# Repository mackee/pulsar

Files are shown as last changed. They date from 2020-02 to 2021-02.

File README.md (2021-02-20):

# Pulsar - The functional keyboard for creators

## 部品の不足や不具合, その他のお問い合わせ

Twitterの私のアカウントまでDMをしてください [@mackee\_w](https://github.com/mackee_w)

## ビルドガイド

このビルドガイドはRev.2(11キー)版のビルドガイドです。Rev.1(9キー+OLED付き) のビルドガイドはこちら

https://gist.github.com/mackee/b5231e5609be889129ee4aa5c9ab0aaa

### 同梱しているもの

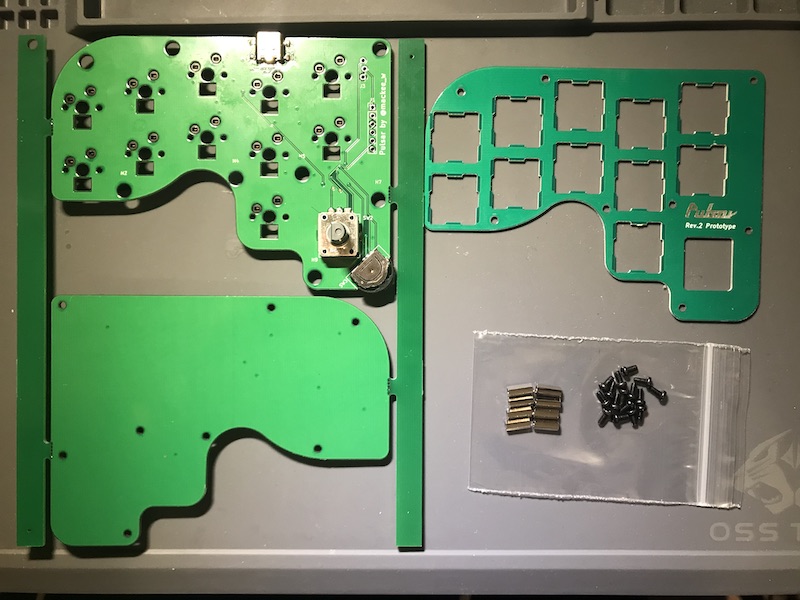
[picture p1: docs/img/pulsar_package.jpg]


#### Pulsar本体基板

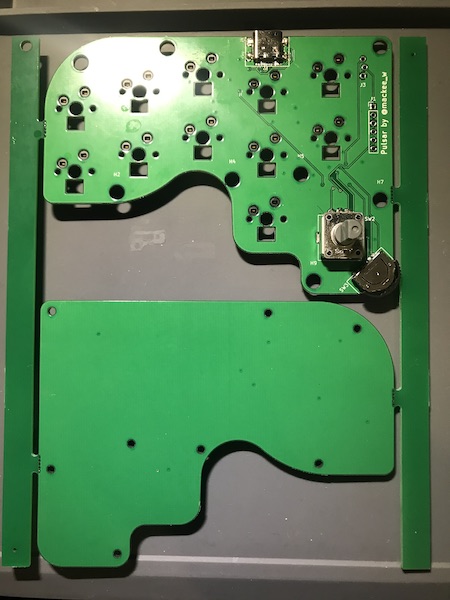
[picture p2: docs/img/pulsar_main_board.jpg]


メイン基板と、LEDがついたボトムプレートが一体になっています。

#### トッププレート

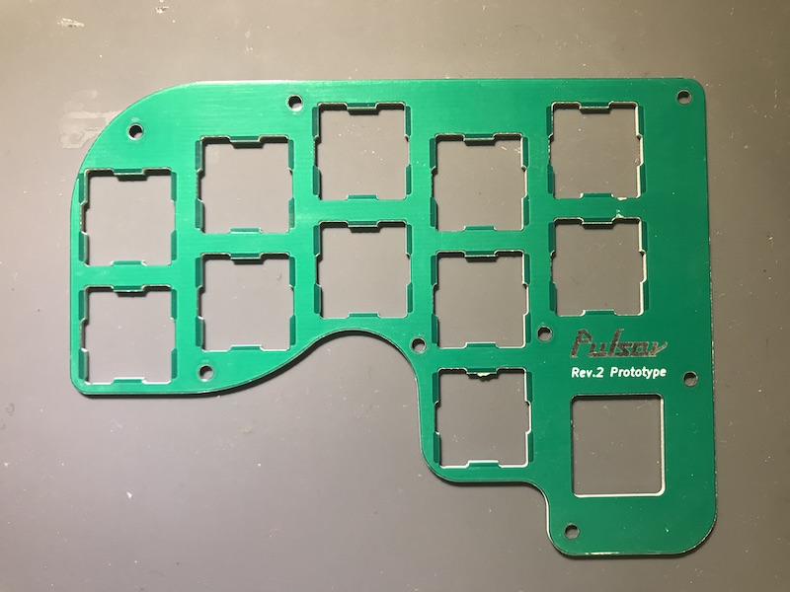
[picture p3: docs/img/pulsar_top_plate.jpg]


本体基板とは別に添付しています。

#### ネジ袋

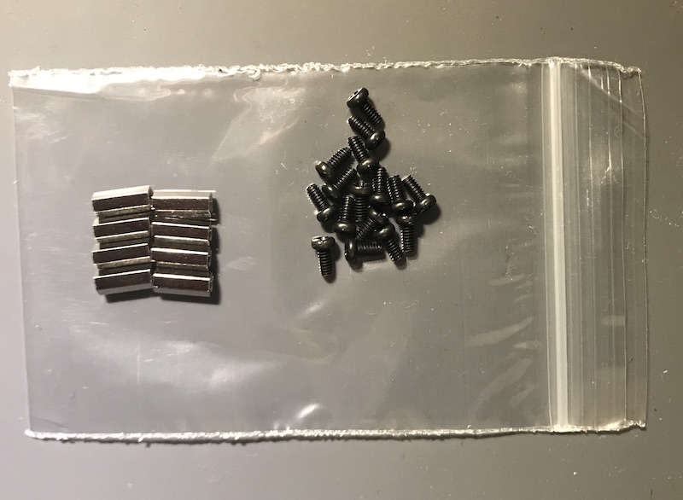
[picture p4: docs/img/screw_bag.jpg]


ネジが入った袋です。袋の中には以下の物が含まれています。

* M2 スペーサー 高さ7.5mm x 8本
* M2 ネジ x 16本

### 別途使用に必要なもの

#### キースイッチ x 11個

Cherry MX互換のキースイッチに対応しています。

[Kailh BOX](https://yushakobo.jp/shop/kailh-box/), [Kailh Speed](https://yushakobo.jp/shop/kailh-speed/), [Gateronスイッチ](https://yushakobo.jp/shop/a0200ga/)の適合を確認しています

#### キーキャップ x 11個

入手されたキースイッチに適合するキーキャップが必要です

#### ノブ/つまみ

親指ロータリーエンコーダ部分に使用するノブです。

軸φ6.1に対応しているつまみが使用できます。また、直径2.3cm以上のつまみはキーキャップと干渉します。

秋月電子で売られている[K-59](http://akizukidenshi.com/catalog/g/gP-12529/)や、千石電商で扱いがある[BR-20](https://www.sengoku.co.jp/mod/sgk_cart/detail.php?code=6A8D-DNEV)が使用できることを確認しています。

### 別途組み立てに必要な道具

* \+ 精密ドライバー
* ラジオペンチ

### 組み立て方

#### 1. 基板を分割する

Pulsar基板本体をメイン基板とボトムプレートに分割します。

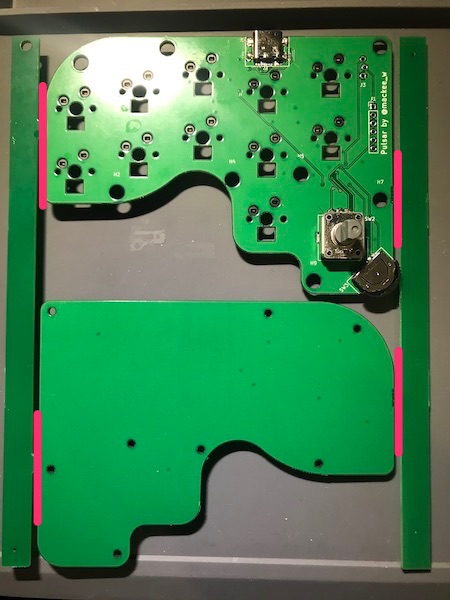
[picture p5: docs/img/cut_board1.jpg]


4箇所あるので、できるだけ近い部分を持ちつつ折ってください。写真のようにラジオペンチを使うときれいに折れます。

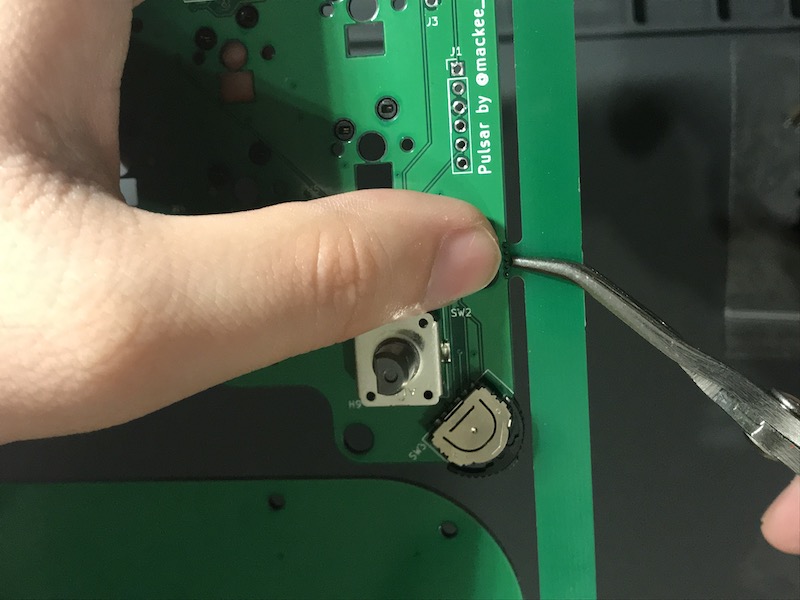
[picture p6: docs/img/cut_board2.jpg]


#### 2. ボトムプレートにスペーサーを立てる

ネジ袋からスペーサーを8個全部と、黒いネジを8個取り出します。

ボトムプレートの何も部品がない面から、ネジを差し込み、反対側からスペーサーを取り付けます。

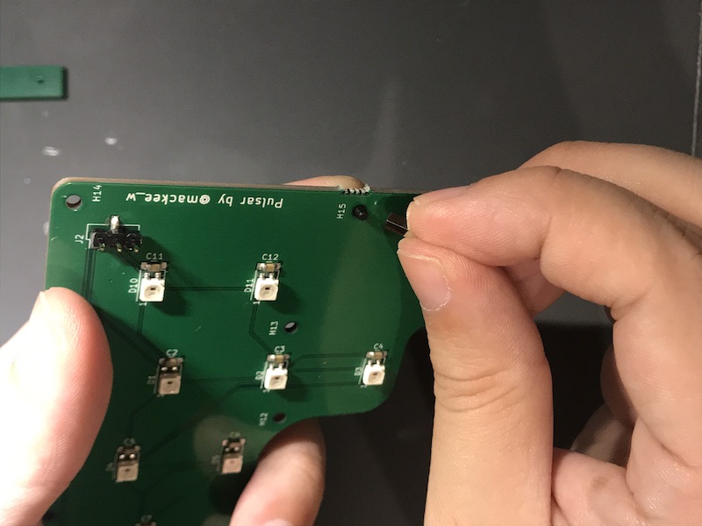
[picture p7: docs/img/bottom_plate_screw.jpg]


このとき、はじめは手で軽く締めていって、最後に精密ドライバーでネジを、ラジオペンチでスペーサーを持って固く締めます。

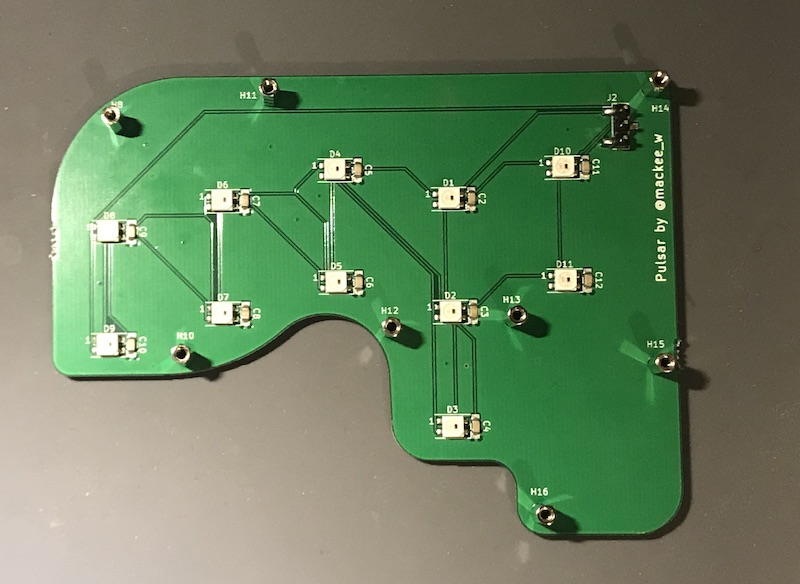
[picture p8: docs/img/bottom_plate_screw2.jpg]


8箇所ある穴すべてにスペーサーを立てます。

#### 3. メイン基板をボトムプレートに重ねる

メイン基板を、スペーサーを立てたボトムプレートの上に重ねます。

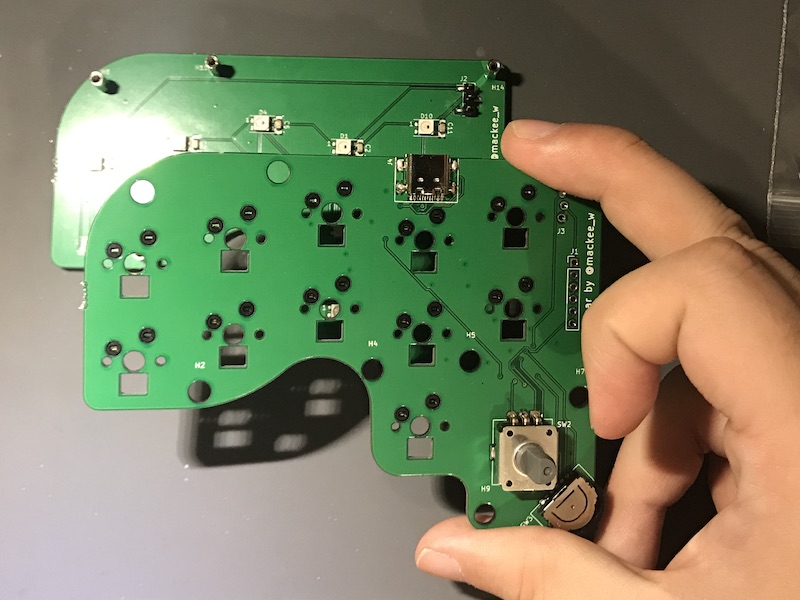
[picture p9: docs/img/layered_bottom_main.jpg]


メイン基板の取り付け穴はスペーサーの直径よりも大きいので、穴の中にスペーサーを通すようにします。

また、ロータリーエンコーダを右下にしたときに、ボトムプレートには 3本のピンヘッダーが、メイン基板にはピンヘッダを通すための穴があります。

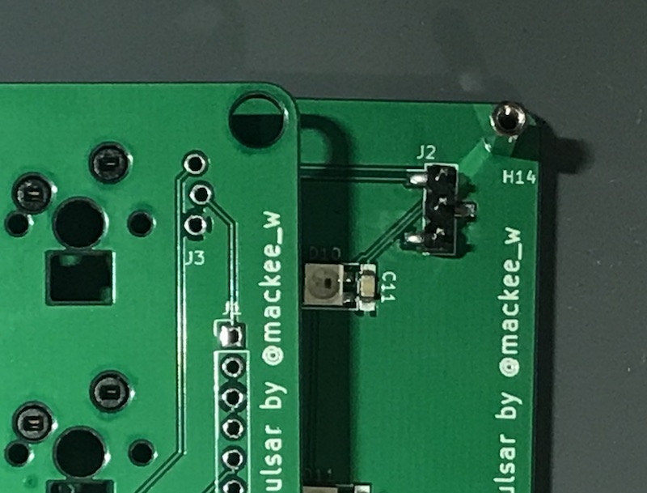
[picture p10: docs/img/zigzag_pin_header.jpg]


電気的に接触するため、メイン基板側の真ん中の穴が少しずれています。重ねたときに、ボトムプレートのピンがメイン基板の穴に刺さるようにします。

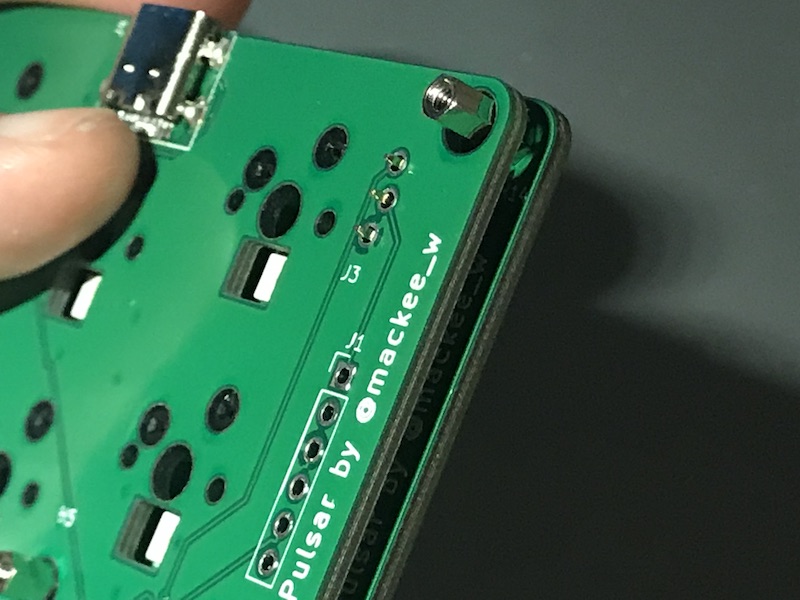
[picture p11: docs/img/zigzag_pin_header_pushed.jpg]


止まるまでグググッと押し込みます。

#### 4. トッププレートを取り付ける

ボトムプレートに、メイン基板を重ねた物の上にさらに、トッププレートを重ねます。

スペーサーの位置とトッププレートの位置を合わせて、トッププレートを残りのネジで固定します。

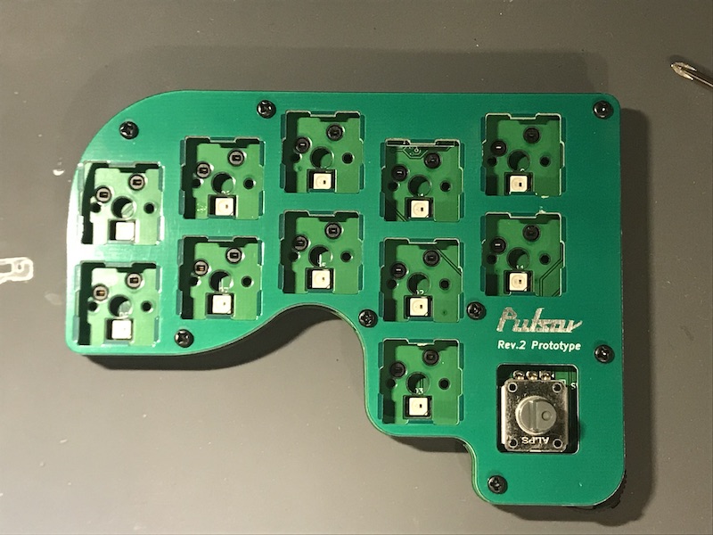
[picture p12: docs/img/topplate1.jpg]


これで、Pulsarの本体は完成です。

#### 5. キースイッチを取り付ける

トッププレートの穴から、キースイッチを差し込んでいきます。

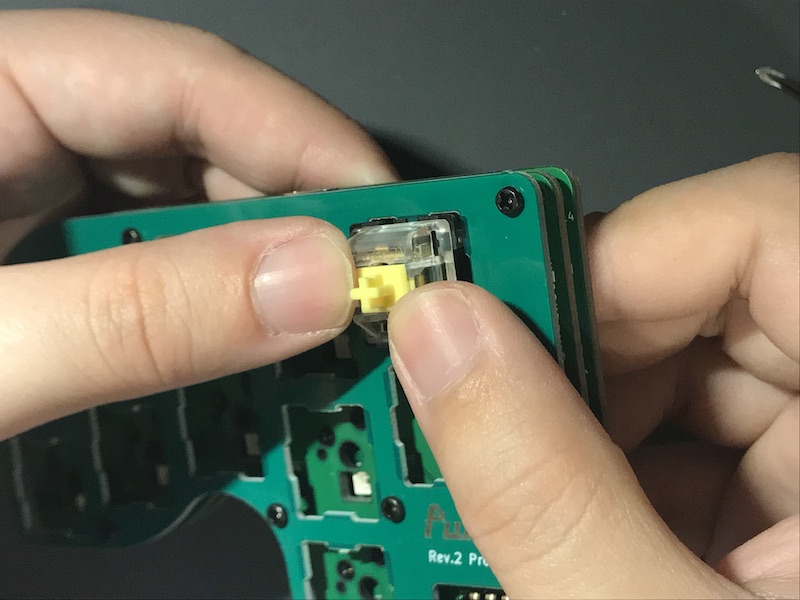
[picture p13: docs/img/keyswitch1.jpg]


このとき、メイン基板の黒い丸の部品と、キースイッチのピンの位置を合わせます。

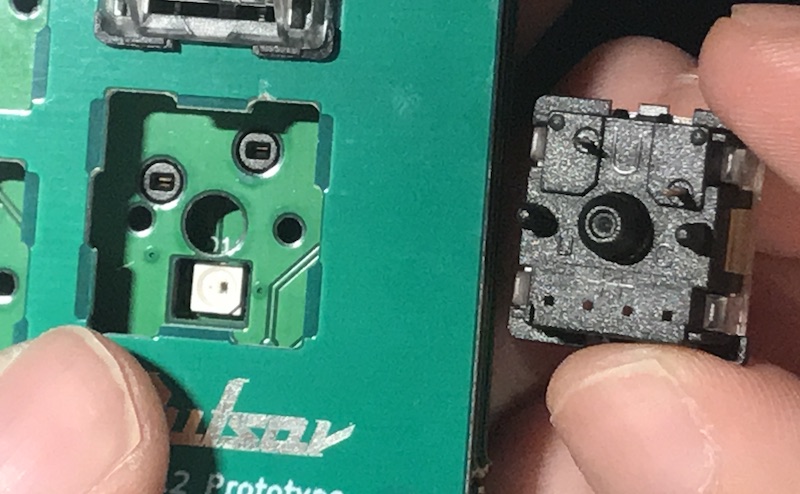
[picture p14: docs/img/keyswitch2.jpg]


また、キースイッチのピンが曲がっているときは、差し込んだときに折れてしまうことがあるため、ラジオペンチなどでまっすぐにしておきます。

トッププレートと、キースイッチの縁が当たるまで、強く押し込みます。

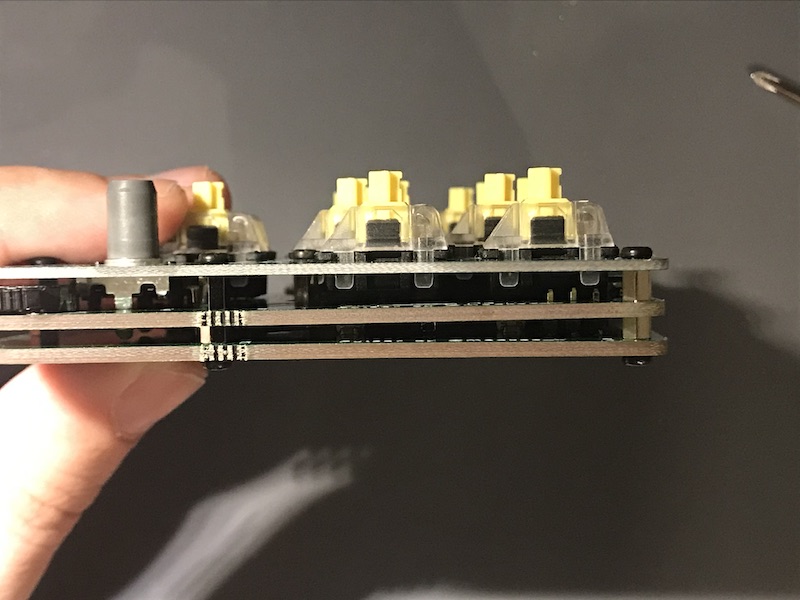
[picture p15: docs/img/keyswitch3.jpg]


#### 6. キーキャップを取り付ける

キースイッチにキーキャップを取り付けます。

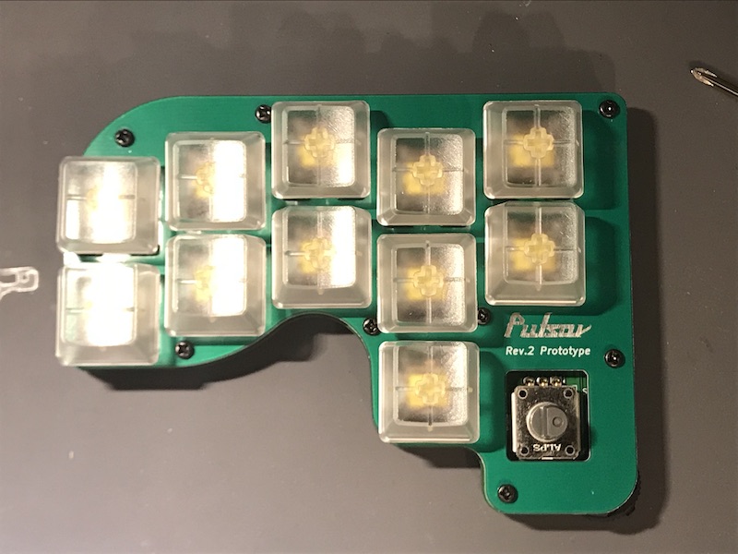
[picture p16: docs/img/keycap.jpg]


#### 7. つまみ/ノブを取り付ける

ロータリーエンコーダにつまみ/ノブを取り付けます。

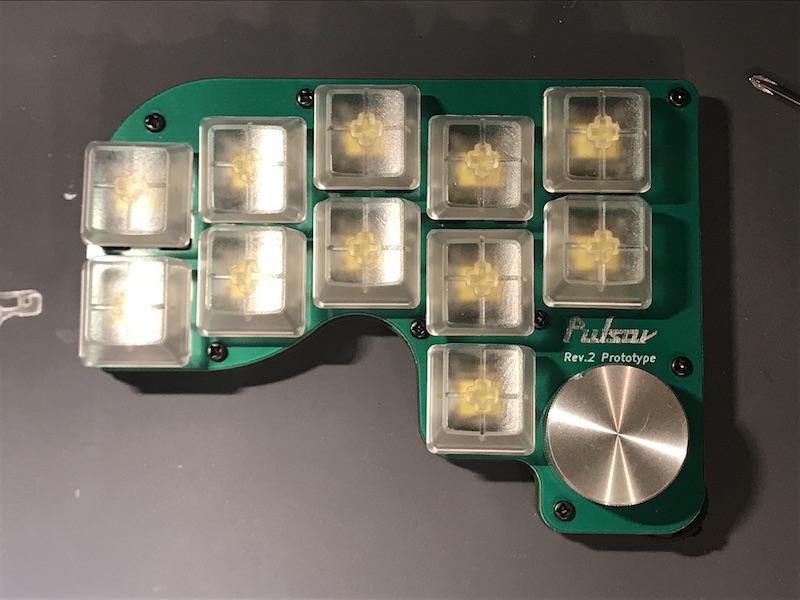
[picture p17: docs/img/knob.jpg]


これで完成です！ お疲れさまでした。

## デフォルトキーマップ

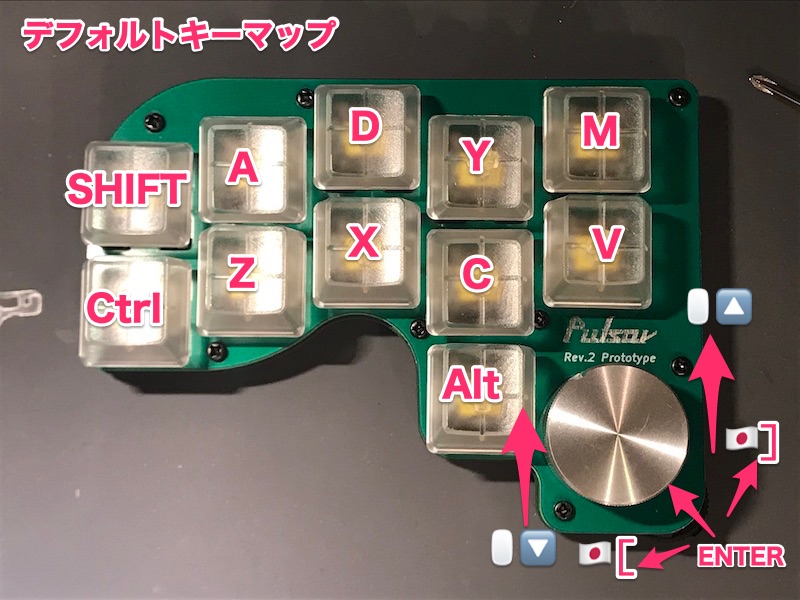
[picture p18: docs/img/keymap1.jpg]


レバースイッチ押し込みを続けるとLED/RESETレイヤーに入ります。

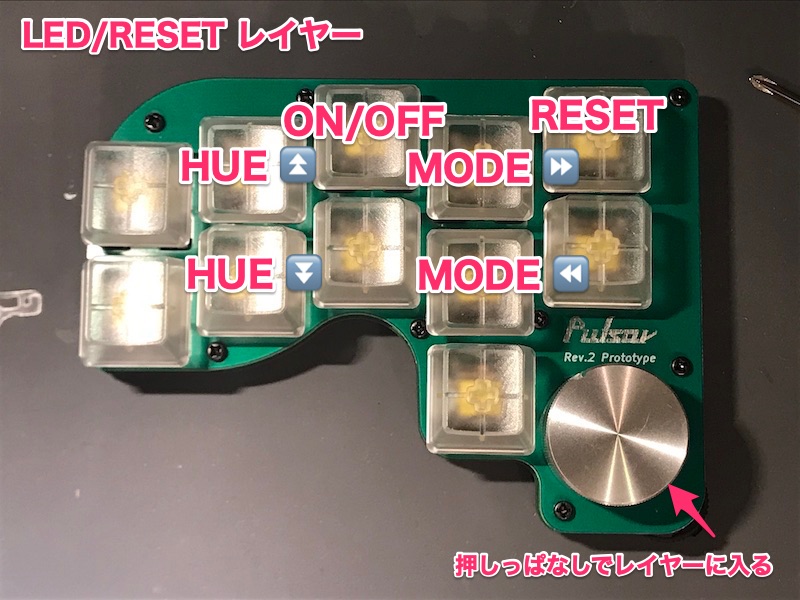
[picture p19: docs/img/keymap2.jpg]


## キーマップ変更方法

**NOTICE: 本家qmk_firmwareへPull Request予定です。マージされたあとに手順が変わります**

qmk configuratorは現在ロータリーエンコーダに対応していないため、ソースコードを変更してキーマップを変える手順を記述します。

事前に`qmk_firmware`を扱える環境を構築しておきます。

[はじめに - QMK Firmware](https://docs.qmk.fm/#/ja/newbs_getting_started)

参考: [QMK 環境の構築](https://github.com/qmk/qmk_firmware/blob/master/docs/ja/newbs_getting_started.md)

### 1. `pulsar` ブランチを指定して `github.com/mackee/qmk_firmware`をcloneします。

```console
$ git clone -b pulsar github.com/mackee/qmk_firmware
```

すでに`qmk_firmware`のclone済みブランチがある場合は、

```console
$ git remote add mackee https://github.com/mackee/qmk_firmware
$ git fetch mackee pulsar
$ git checkout pulsar
```

と、リモートリポジトリを追加してcheckoutします。

### 2. ファームウェアを書き込む

動作確認のためにファームウェアを書き込みます。頒布時点で書き込まれているキーマップは`default`です。

`qmk_firmware`のディレクトリにCLIターミナル内で移動し、以下のコマンドを実行します。

```console
$ make pulsar/rev2:default:dfu-util
$ qmk flash -kb pulsar/rev2 -km default
```

`ERROR: Bootloader not found. Trying again in 5s.` と表示されたら、右下レバースイッチを押し込みながら、一番右上のキーを押します。すると、書き込みが開始されます。

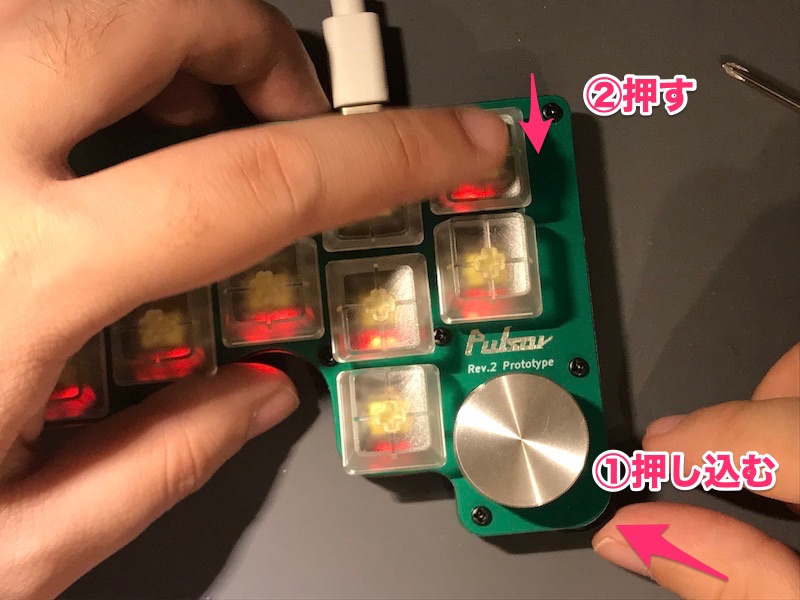
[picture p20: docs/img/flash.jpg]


`Transitioning to dfuMANIFEST state` と表示されたら成功です。

### 3. キー配置を変更する

`default`キーマップをもとにキー配置を変えてみます。

まず、`keyboard/pulsar/keymaps/rev2/default`ディレクトリをコピーして`keyboard/pulsar/rev2/keymaps/mykeymap`ディレクトリを作ります。

```console
$ cp -R keyboard/pulsar/rev2/keymaps/default keyboard/pulsar/rev2/keymaps/mykeymap
```

その後にお好きなテキストエディタで`keyboard/pulsar/rev2/keymaps/mykeymap/keymap.c`を編集します。

例えば`S`と入力されるように設定しているキーを`D`に変更するには以下のように`keymap.c`を変更します。

```diff
@@ -28,7 +28,7 @@ enum {

 const uint16_t PROGMEM keymaps[][MATRIX_ROWS][MATRIX_COLS] = {
   [_BASE] = LAYOUT( /* Base */
-    KC_LSHIFT, KC_A,    KC_S,     KC_Y,    KC_M,             \
+    KC_LSHIFT, KC_A,    KC_D,     KC_Y,    KC_M,             \
     KC_LCTRL,  KC_Z,    KC_X,     KC_C,    KC_V,             \
                                   KC_LALT,                   \
     JP_LBRC,   XXXXXXX, LT(_LED, KC_ENTER), XXXXXXX, JP_RBRC \
```

キーコードの参考ドキュメント: [キーコードまとめ](https://syon.github.io/refills/rid/1471100/)

キーマップの最下段はレバースイッチのキーマップです。レバースイッチには半押しも検知できる機能があるのですが、使いにくいため`default`キーマップでは使っていません。

`JP`がプレフィックスにあるキーコードは、日本語キーボード向けのキーコードです。Windowsですでに日本語キーボードが別にある環境で利用してください。

保存後にキーボードにキーマップを書き込むには、 2と同様の手順で、以下のコマンドを実行します。

```console
$ qmk flash -kb pulsar/rev2 -km mykeymap
```

### 4. ロータリーエンコーダの挙動を変更する

ロータリーエンコーダは`keymap.c`内の`encoder_update_user`関数で挙動を定義しています。

```c
void encoder_update_user(uint8_t index, bool clockwise) {
  if (index == 0) {
    if (clockwise) {
      if (get_mods() & MOD_LCTL) {
        rgblight_step();
      } else if (get_mods() & MOD_LSFT) {
        tap_code(KC_END);
      } else {
        tap_code(KC_MS_WH_DOWN);
      }
    } else {
      if (get_mods() & MOD_LCTL) {
        rgblight_step_reverse();
      } else if (get_mods() & MOD_LSFT) {
        tap_code(KC_HOME);
      } else {
        tap_code(KC_MS_WH_UP);
      }
    }
  }
}
```

`KC_`から始まるキーコードを変更すれば、そのまま挙動を変えることが出来ます。

`clockwise`が`true`の場合は時計回り、`false`のときは反時計回りの場合です。また、`get_mods() & MOD_***`では装飾キーの同時押しの場合の挙動を記述しています。

### LICENSE

#### ハードウェア

回路図, パーツリスト, 基板配線図などハードウェア部分

<br />この 作品 は <a rel="license" href="http://creativecommons.org/licenses/by-sa/4.0/">クリエイティブ・コモンズ 表示 - 継承 4.0 国際 ライセンス</a>の下に提供されています。

#### ソフトウェア

本製品のファームウェアは[qmk firmwareのライセンス](https://qmk.fm/license/)に従います。

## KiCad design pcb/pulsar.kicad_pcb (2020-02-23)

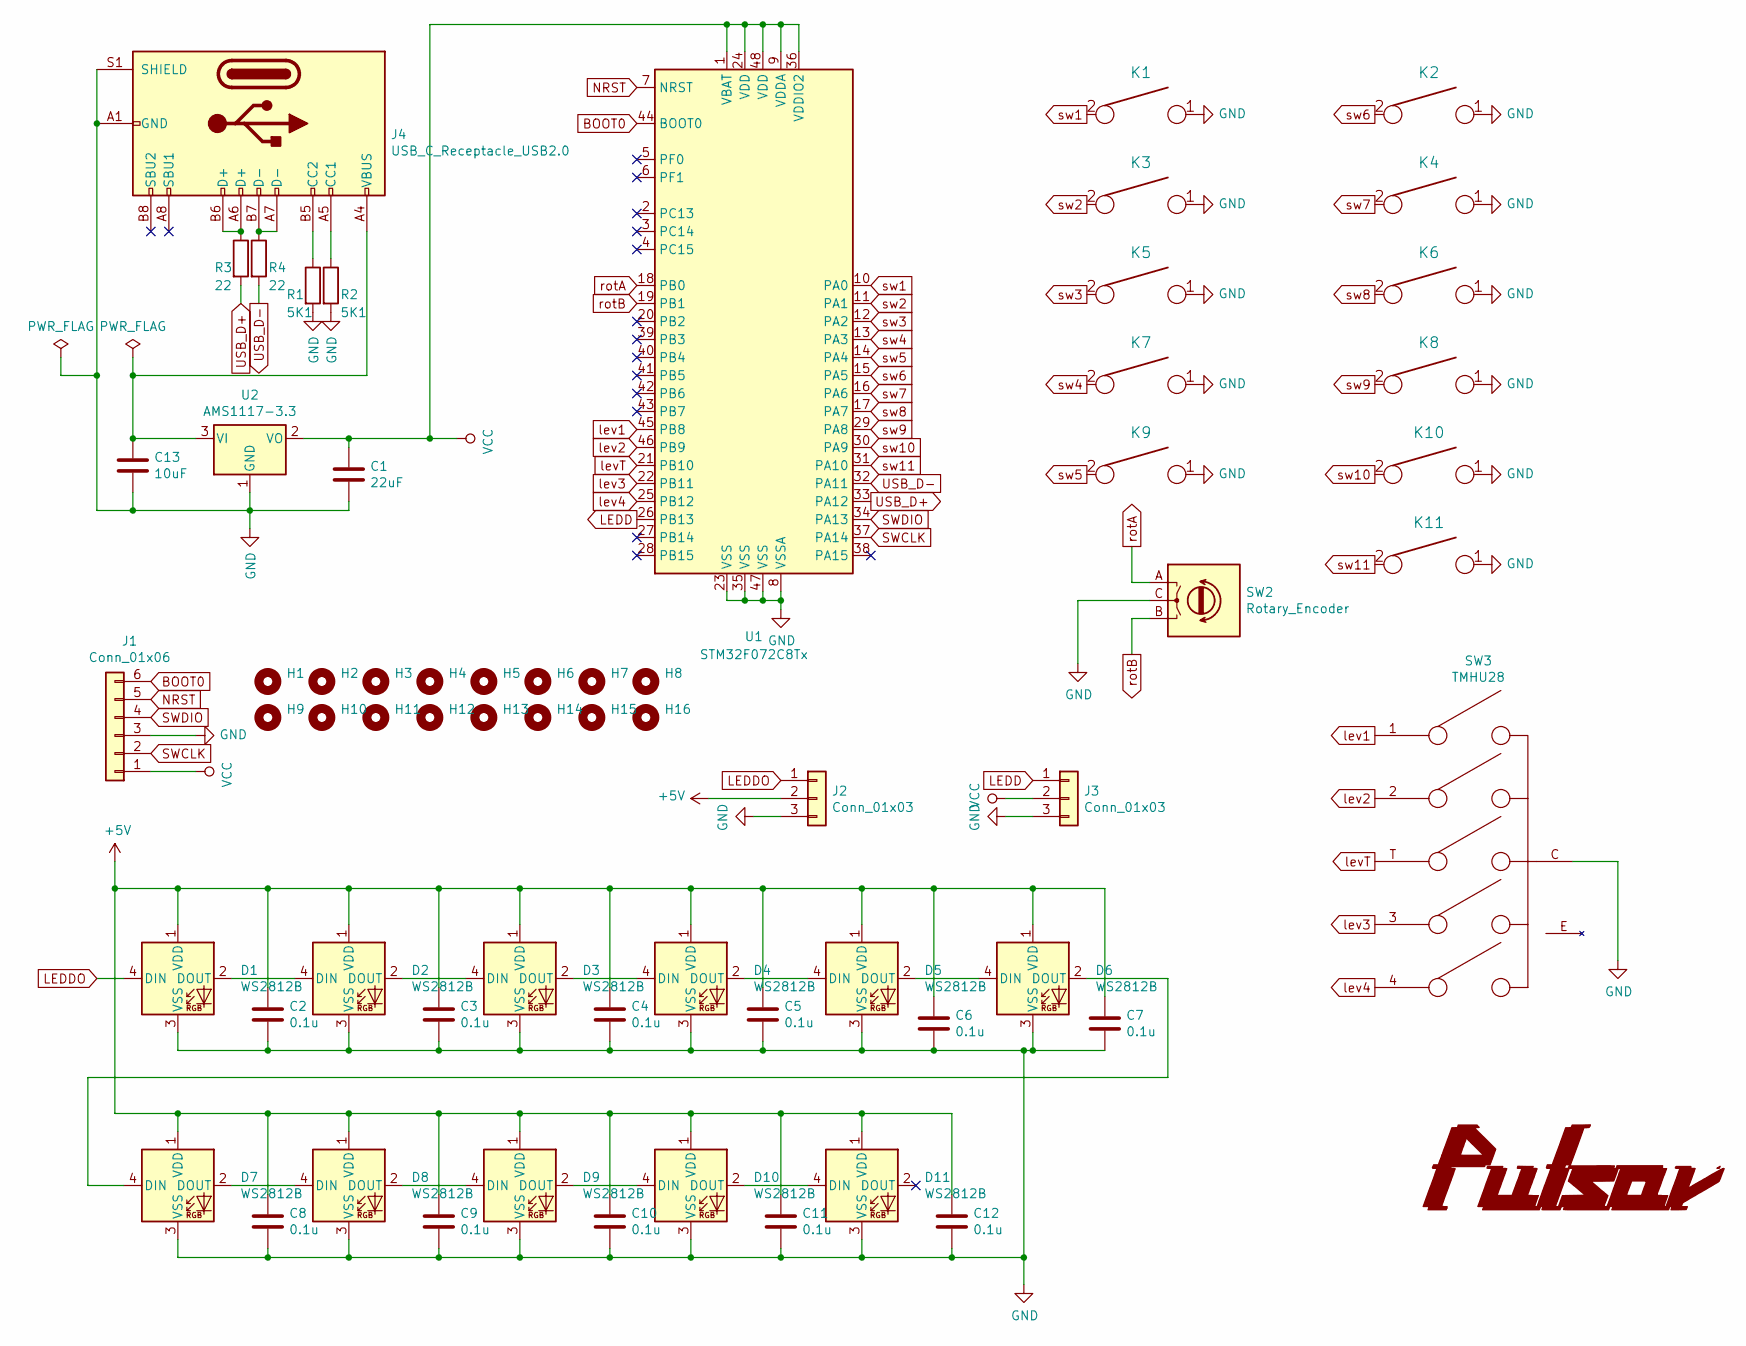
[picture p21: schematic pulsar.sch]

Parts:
C1: 22uF; C_0805_HandSoldering
C2, C3, C4, C5, C6, C7, C8, C9, C10, C11, C12: 0.1u; C_0805_HandSoldering
C13: 10uF; C_0805_HandSoldering
D1, D2, D3, D4, D5, D6, D7, D8, D9, D10, D11: WS2812B; LED_SK6812MINI_PLCC4_3.5x3.5mm_P1.75mm
H1, H2, H3, H4, H5, H6, H7, H9: MountingHole; MountingHole_4.3mm_M4
H8, H10, H11, H12, H13, H14, H15, H16: MountingHole; MountingHole_2.2mm_M2
J1: Conn_01x06; Pin_Header_Straight_1x06_Pitch2.54mm
J2: Conn_01x03; Pin_Header_Straight_1x03_Pitch2.54mm_SMD_Pin1Left
J3: Conn_01x03; 3pin-zigzag
J4: USB_C_Receptacle_USB2.0; Mid_Mount-USB_C_HandSoldering
K1, K2, K3, K4, K5, K6, K7, K8, K9, K10, K11: KEYSW; Kailh_socket
R1, R2: 5K1; R_0805_HandSoldering
R3, R4: 22; R_0805_HandSoldering
SW2: Rotary_Encoder; RotaryEncoder_Alps_EC12E_Vertical_H20mm
SW3: TMHU28
U1: STM32F072C8Tx; LQFP-48_7x7mm_Pitch0.5mm
U2: AMS1117-3.3; SOT-223-3_TabPin2

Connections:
+5V: C2.1, C3.1, C4.1, C5.1, C6.1, C7.1, C8.1, C9.1, C10.1, C11.1, C12.1, D1.1 (VDD), D2.1 (VDD), D3.1 (VDD), D4.1 (VDD), D5.1 (VDD), D6.1 (VDD), D7.1 (VDD), D8.1 (VDD), D9.1 (VDD), D10.1 (VDD), D11.1 (VDD), J2.2
BOOT0: J1.6, U1.44 (BOOT0)
GND: C1.2, C2.2, C3.2, C4.2, C5.2, C6.2, C7.2, C8.2, C9.2, C10.2, C11.2, C12.2, C13.2, D1.3 (VSS), D2.3 (VSS), D3.3 (VSS), D4.3 (VSS), D5.3 (VSS), D6.3 (VSS), D7.3 (VSS), D8.3 (VSS), D9.3 (VSS), D10.3 (VSS), D11.3 (VSS), J1.3, J2.3, J3.3, J4.A1 (GND), J4.A12 (GND), J4.B1 (GND), J4.B12 (GND), J4.S1 (SHIELD), K1.1, K2.1, K3.1, K4.1, K5.1, K6.1, K7.1, K8.1, K9.1, K10.1, K11.1, R1.2, R2.2, SW2.C, SW3.C, U1.8 (VSSA), U1.23 (VSS), U1.35 (VSS), U1.47 (VSS), U2.1 (GND)
LEDD: J3.1, U1.26 (PB13)
LEDDO: D1.4 (DIN), J2.1
NRST: J1.5, U1.7 (NRST)
unnamed: C13.1, J4.A4 (VBUS), J4.A9 (VBUS), J4.B4 (VBUS), J4.B9 (VBUS), U2.3 (VI)
unnamed: D1.2 (DOUT), D2.4 (DIN)
unnamed: D2.2 (DOUT), D3.4 (DIN)
unnamed: D3.2 (DOUT), D4.4 (DIN)
unnamed: D4.2 (DOUT), D5.4 (DIN)
unnamed: D5.2 (DOUT), D6.4 (DIN)
unnamed: D6.2 (DOUT), D7.4 (DIN)
unnamed: D7.2 (DOUT), D8.4 (DIN)
unnamed: D8.2 (DOUT), D9.4 (DIN)
unnamed: D10.2 (DOUT), D11.4 (DIN)
unnamed: D9.2 (DOUT), D10.4 (DIN)
unnamed: J4.A5 (CC1), R2.1
unnamed: J4.A6 (D+), J4.B6 (D+), R3.1
unnamed: J4.A7 (D-), J4.B7 (D-), R4.1
unnamed: J4.B5 (CC2), R1.1
SWCLK: J1.2, U1.37 (PA14)
SWDIO: J1.4, U1.34 (PA13)
USB_D+: R3.2, U1.33 (PA12)
USB_D-: R4.2, U1.32 (PA11)
VCC: C1.1, J1.1, J3.2, U1.1 (VBAT), U1.9 (VDDA), U1.24 (VDD), U1.36 (VDDIO2), U1.48 (VDD), U2.2 (VO)
lev1: SW3.1, U1.45 (PB8)
lev2: SW3.2, U1.46 (PB9)
lev3: SW3.3, U1.22 (PB11)
lev4: SW3.4, U1.25 (PB12)
levT: SW3.T, U1.21 (PB10)
rotA: SW2.A, U1.18 (PB0)
rotB: SW2.B, U1.19 (PB1)
sw1: K1.2, U1.10 (PA0)
sw2: K3.2, U1.11 (PA1)
sw3: K5.2, U1.12 (PA2)
sw4: K7.2, U1.13 (PA3)
sw5: K9.2, U1.14 (PA4)
sw6: K2.2, U1.15 (PA5)
sw7: K4.2, U1.16 (PA6)
sw8: K6.2, U1.17 (PA7)
sw9: K8.2, U1.29 (PA8)
sw10: K10.2, U1.30 (PA9)
sw11: K11.2, U1.31 (PA10)

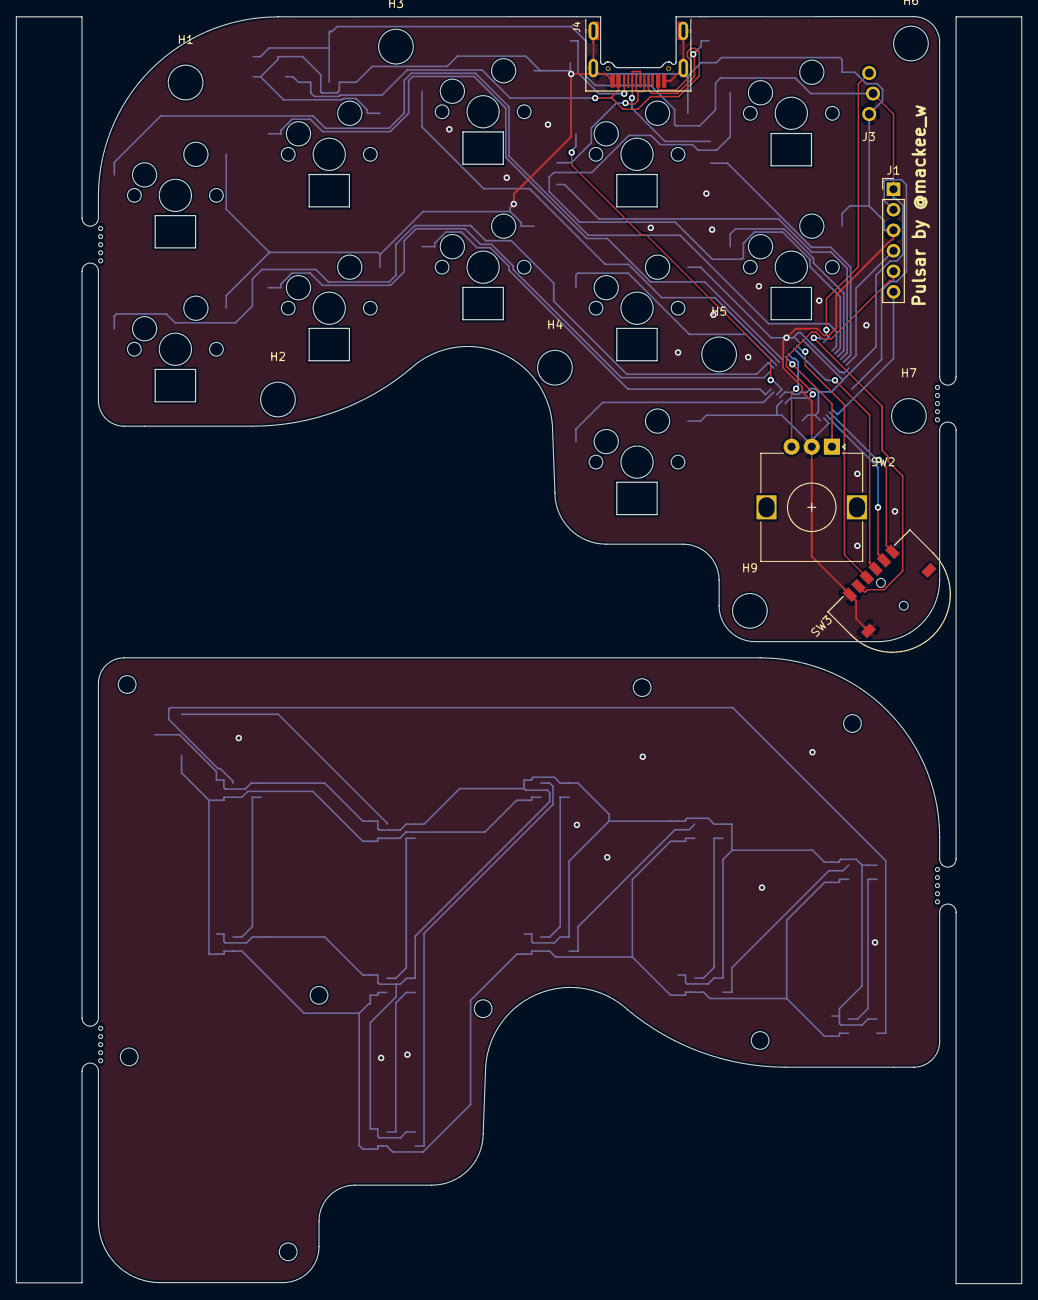
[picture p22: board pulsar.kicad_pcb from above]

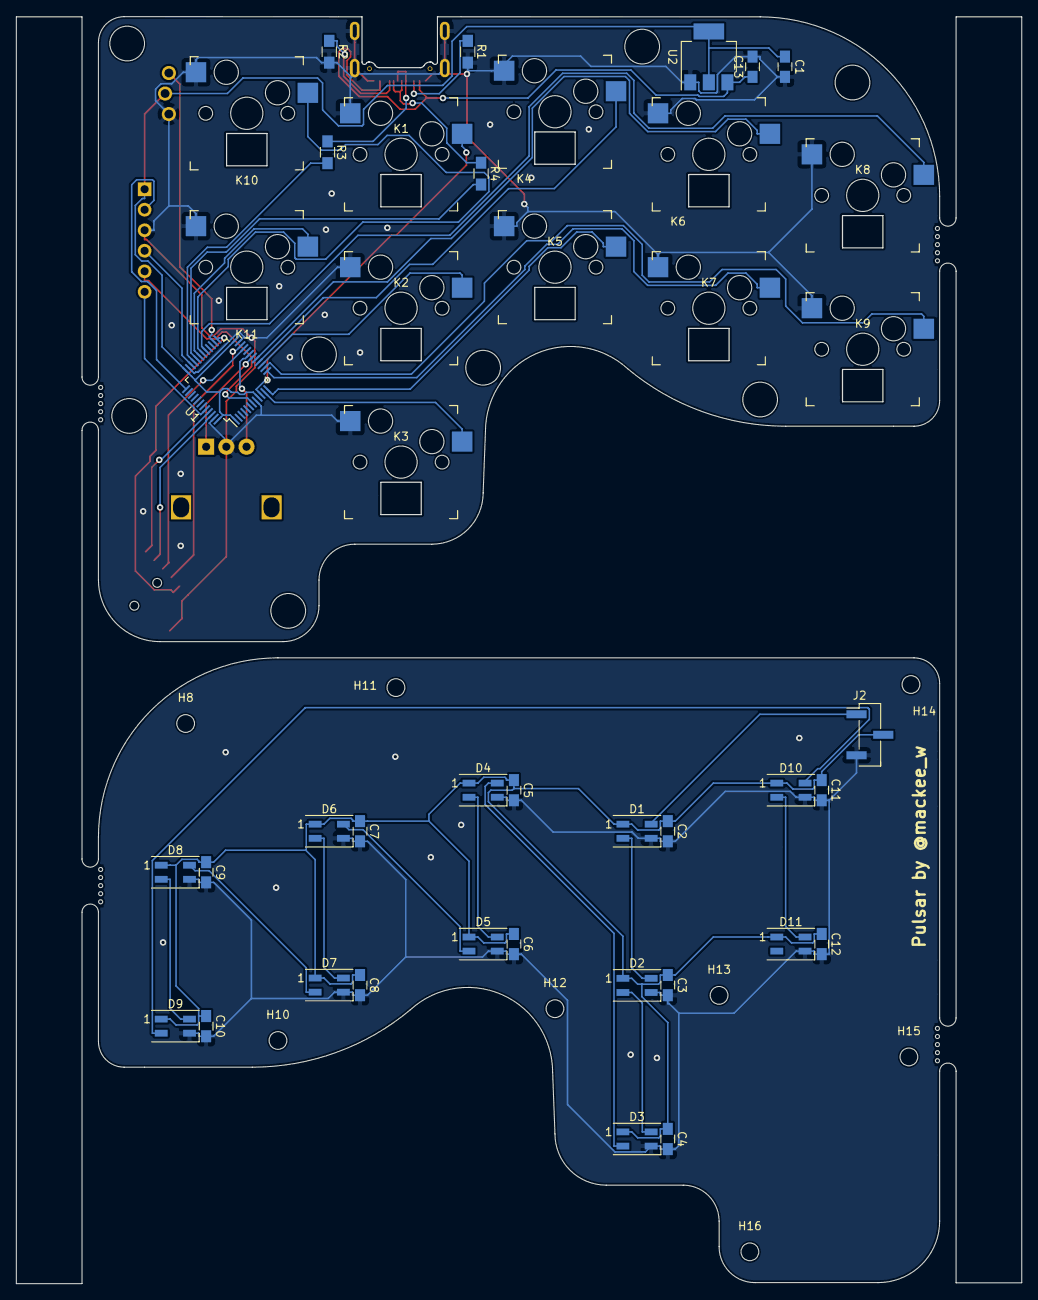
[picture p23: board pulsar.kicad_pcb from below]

Board: 2 copper layers, 124.5 x 156.8 mm, 63 parts (39 on the bottom side), 44 nets.

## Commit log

2019-11-03 pulsar rev1
    [pulsar.kicad_pcb, pulsar.sch]
2020-02-23 update pcb: rev2.0 - 11 keys
    [pulsar.kicad_pcb, pulsar.sch]
2020-03-15 add plate pcb
    [pulsar.sch, pulsar_plate.kicad_pcb]
2021-02-20 qmkの導入に関して公式の和訳ドキュメントとqmkコマンドを使うようにした

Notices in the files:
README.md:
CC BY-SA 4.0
